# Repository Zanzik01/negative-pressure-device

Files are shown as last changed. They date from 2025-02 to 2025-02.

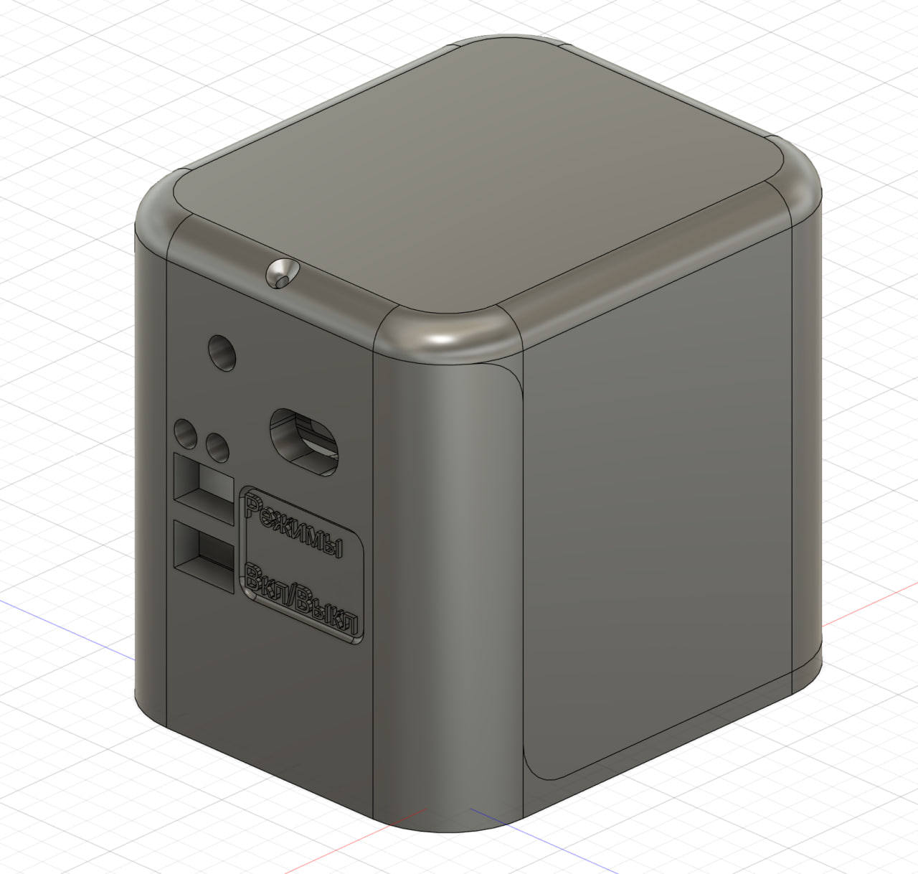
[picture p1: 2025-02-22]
images/View of the simulated assembly.jpg

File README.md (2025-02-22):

# negative-pressure-device

Меня попросили сделать небольшой аппарат, суть которого заключается в том, чтобы откачивать воздух из определенной области, создавая вакуум определенного уровня. Как уточнил позже заказчик таких уровней должно быть два. Также в пожелания заказчика входила простота интерфейса и автономность.

## Комплектующие

Так как функционал у устройства небольшой, то подойдет один из самых простых и удобных МК, а именно Arduino Nano. Вакуумный мотор мне предоставил заказчик, поэтому для начала работы оставалось добавить только драйвер коллекторного мотора. У меня это DRV8833. Для измерения давления понадобится барометр - BMP280. Дальше понадобится два тумблера, два светодиода, аккумулятор, плата заряда и немного мелочи, такой как резисторы. Для соединения всего этого воедино я спаяла всё на макетной плате, с помощью коннекторов я обеспечила себе возможность заменяемости компонентов. Мне это показалось необходимым, так как данное устройство лишь прототип. Также думаю стоит упомянуть, что для измерения давления в системе баррометр был помещен в пластиковый кейс, который после был загерметизирован.

## Программа

Алгоритм работы программы крайне прост. Для начала, нажатием черной кнопки (переводим тумблер из положения 0 в положение -), подаем питание в систему, при включении производится проверка инициализации барометра. Если она по какой-то причине не проходит, то загорается красный светодиод. Если всё проходит успешно, то загорается зеленый светодиод. Далее мотор начинает выкачивать воздух, если белый тумблер в первом режиме, то мотор работает до первого установленного значения вакуума, если тумблер установлен во втором положении, то мотор создает вакуум пока значения барометра не достигнут второго установленного значения вакуума. Но не стоит забывать, что мотор может работать достаточно долго, а целевого значения не достигать, например, если в система разгерметизированна. С точки зрения программы мы ничего не теряем, но так как мотор это нечто физическое, которому сложно работать долгое время без остановки, то стоит учитывать этот момент в программе. Также неприрывная работа плохо сказывается на автономности прибора. На такой случай был предусмотрен следующий сценарий. При включении можно начать засекать время, и если время на таймере выходит за рамки таймаута, то мотор выключается вне зависимости от значения барометра.

Фотографии данного проекта я приложила в отдельной папке, если кому-то интересно, то можете найти их там)

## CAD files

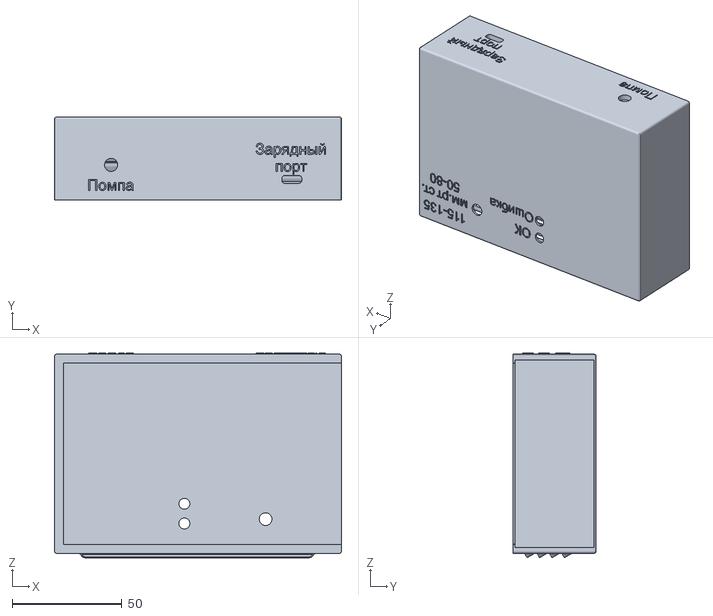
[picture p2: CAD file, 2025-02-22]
models/Cover V1.0.stl
130.8 x 38.0 x 93.2

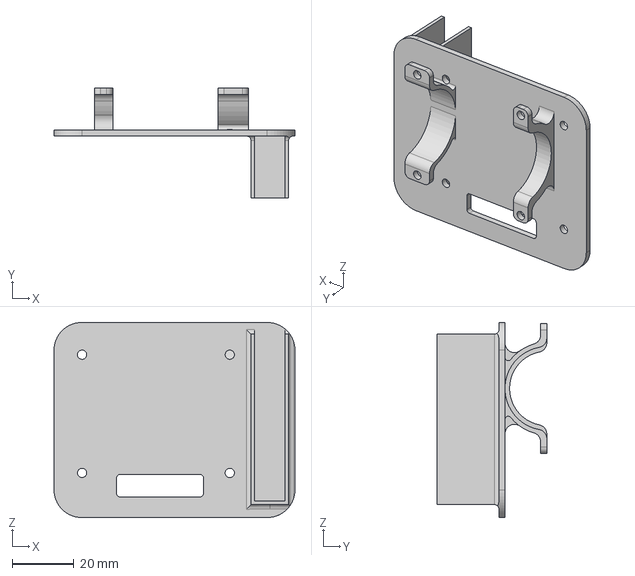
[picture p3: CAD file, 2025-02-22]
models/STEP/2nd floor V2.1.step
78.1 x 35.5 x 63.2 mm

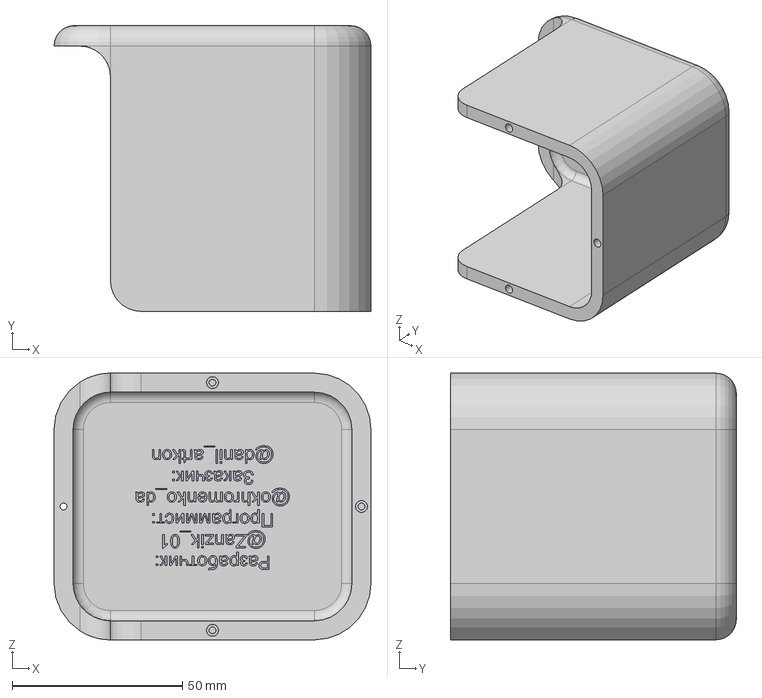
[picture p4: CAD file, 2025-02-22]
models/STEP/Cover V2.1.step
93.2 x 84.0 x 78.4 mm

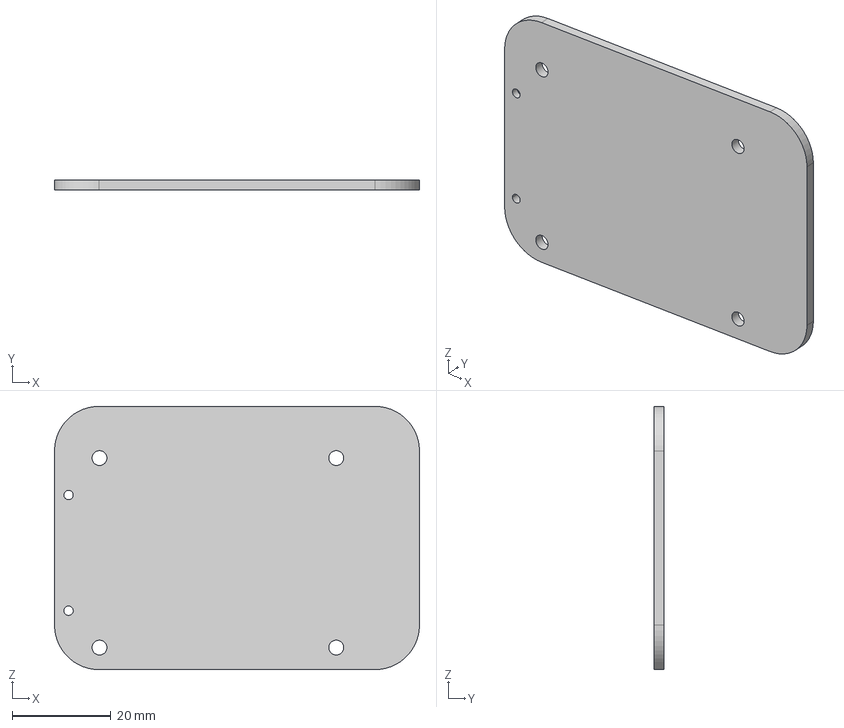
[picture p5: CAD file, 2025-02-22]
models/STEP/3rd floor V2.1.step
73.8 x 2.00 x 53.2 mm

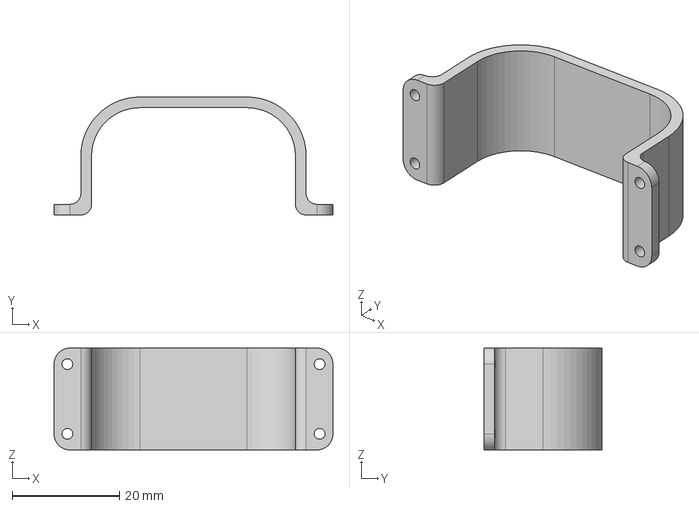
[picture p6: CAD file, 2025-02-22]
models/STEP/Mounting the barometer V2.1.step
52.0 x 22.0 x 19.0 mm

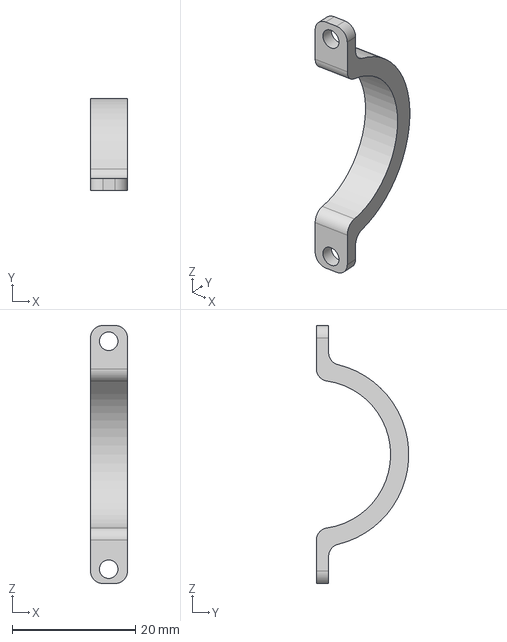
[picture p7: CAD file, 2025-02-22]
models/STEP/The first motor mount V2.1.step
6.00 x 15.0 x 41.9 mm

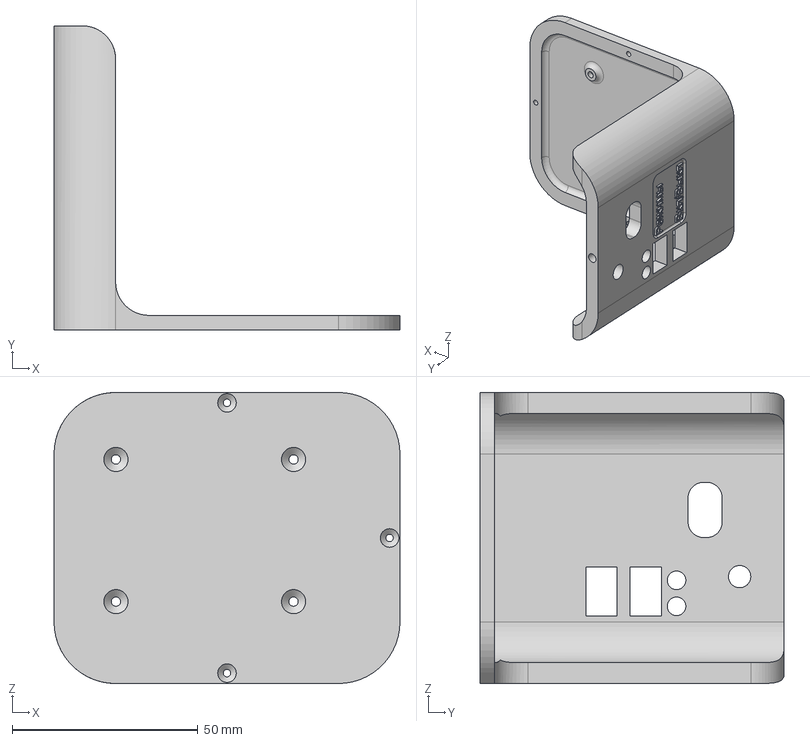
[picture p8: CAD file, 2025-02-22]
models/STEP/Footing V2.1.step
93.2 x 82.0 x 78.4 mm

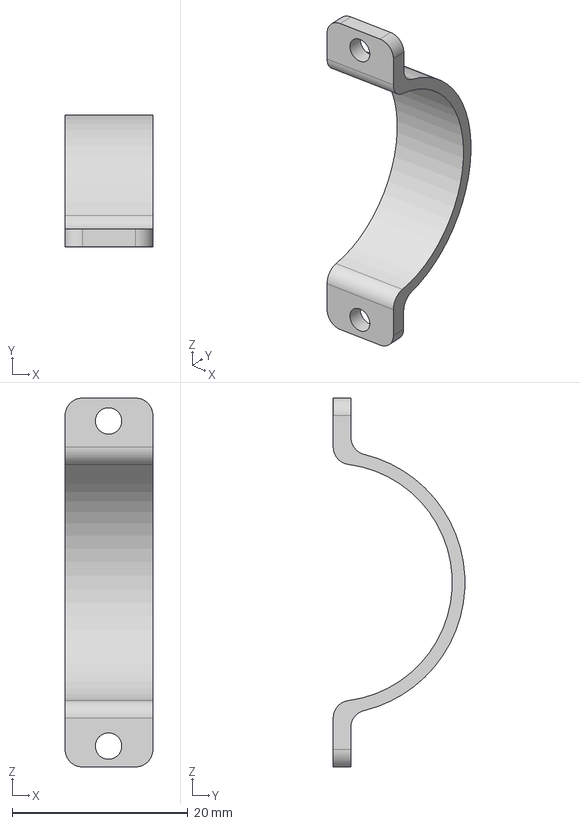
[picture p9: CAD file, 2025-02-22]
models/STEP/The second motor mount V2.1.step
10.0 x 15.0 x 42.0 mm

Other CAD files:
models/STL/2nd floor V2.1.stl
models/STL/3rd floor V2.1.stl
models/STL/Cover V2.1.stl
models/STL/Footing V2.1.stl
models/STL/Mounting the barometer V2.1.stl
models/STL/The first motor mount V2.1.stl
models/STL/The second motor mount V2.1.stl

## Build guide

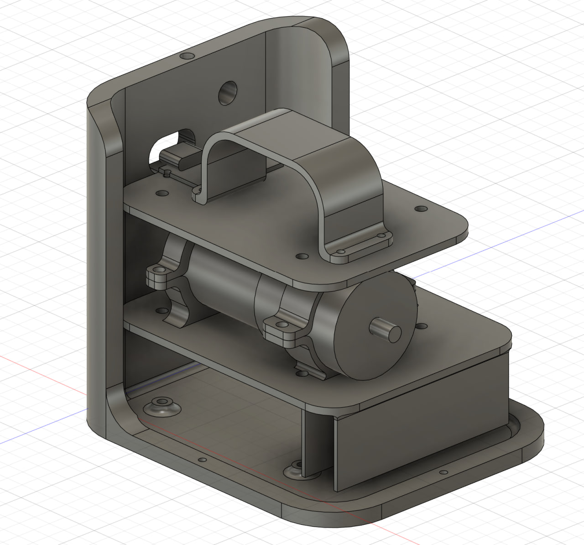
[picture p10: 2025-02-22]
images/View of the assembly from the inside.jpg

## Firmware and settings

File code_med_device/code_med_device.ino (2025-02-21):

#include <VB_BMP280.h> 
 
const byte PIN_LED_RED = 3; 
const byte PIN_LED_GREEN = 4; 
const byte PIN_MOTOR_A = 6; 
const byte PIN_MOTOR_B = 9; 
const byte PIN_MOTOR_SLEEP = 12; 
 
const long TIMEOUT = 60000; 
 
VB_BMP280 barometer; 
 
unsigned long startTimeMotor; 
unsigned long stopTimeMotor; 
 
bool barometer_connection = false; 

byte motorState = 0; 
 
void setupBarometer() { 
  barometer.start_altitude = 0; 
 
  while (!barometer_connection) { 
    barometer_connection = barometer.begin(); 
 
    if (barometer_connection) { 
      return; 
    } else { 
      error(); 
    } 
  } 
} 
 
void setup() { 
  pinMode(PIN_MOTOR_A, OUTPUT); 
  pinMode(PIN_MOTOR_B, OUTPUT); 
  pinMode(PIN_LED_GREEN, OUTPUT);
  pinMode(PIN_LED_RED, OUTPUT);
  pinMode(PIN_MOTOR_SLEEP, OUTPUT); 
 
  digitalWrite(PIN_MOTOR_SLEEP, LOW); 
  setupBarometer(); 

  digitalWrite(PIN_LED_GREEN, HIGH); 
} 
 
void loop() { 
 
  if (barometer_connection) { 
    barometer.read(); 
    float pres = barometer.pres/133.32; 

    if (580 >= pres) { 
      stopMotor(); 
    } else if ((pres >= 720) && (motorState != 1)) { 
      runMotor(); 
    } 
 
    long timer = startTimeMotor - stopTimeMotor; 
    if (abs(timer) >= TIMEOUT) { 
      motorState = 1; 
      stopMotor(); 
      error(); 
    } 
  } 
} 
 
void runMotor() { 
  startTimeMotor = millis(); 
  digitalWrite(PIN_MOTOR_SLEEP, HIGH); 
  analogWrite(PIN_MOTOR_B, 255); 
  digitalWrite(PIN_MOTOR_A, LOW); 
} 
 
void stopMotor() { 
  stopTimeMotor = millis(); 
  digitalWrite(PIN_MOTOR_SLEEP, LOW); 
  analogWrite(PIN_MOTOR_B, LOW); 
  analogWrite(PIN_MOTOR_A, LOW); 
} 
 
void error() { 
  digitalWrite(PIN_LED_RED, HIGH); 
  digitalWrite(PIN_LED_GREEN, LOW); 
}

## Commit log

2025-02-22 Added model cover
    [Cover V1.0.stl]
2025-02-22 Added models
    [2nd floor V2.1.step, 2nd floor V2.1.stl, 3rd floor V2.1.step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]
